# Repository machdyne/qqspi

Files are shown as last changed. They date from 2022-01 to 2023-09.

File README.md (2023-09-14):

# QQSPI Pmod&trade; compatible module

The QQSPI module provides access to four Quad SPI devices via a 12-pin Pmod&trade; compatible interface.

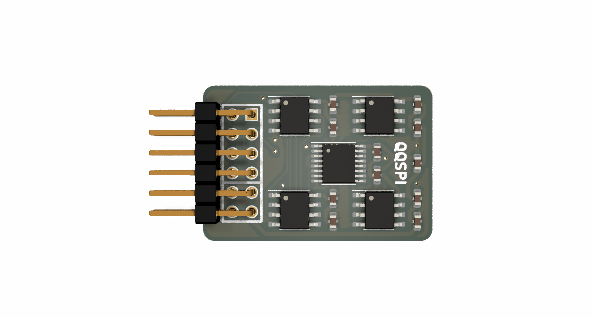
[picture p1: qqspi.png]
QQSPI


This repo contains schematics, pinouts and example Verilog code for the LD-QQSPI-PSRAM32 module.

Find more information on the [LD-QQSPI-PSRAM32 product page](https://machdyne.com/product/qqspi-psram32/).

## Modes

| PMOD/SS | PMODCS0 | PMODCS1 | -> | QSPI1/CE | QSPI2/CE | QSPI3/CE | QSPI4/CE |
| --- | --- | --- | -- | --- | --- | --- | --- |
| H | X | X | -> | H | H | H | H |
| L | L | L | -> | L | H | H | H |
| L | H | L | -> | H | L | H | H |
| L | L | H | -> | H | H | L | H |
| L | H | H | -> | H | H | H | L |

## Pinout

| Pin | Signal |
| --- | --- |
| 1 | /SS (active low) |
| 2 | SIO0 (MOSI) |
| 3 | SIO1 (MISO) |
| 4 | SCK |
| 5 | GND |
| 6 | 3V3 |
| 7 | SIO2 |
| 8 | SIO3 |
| 9 | CS0 |
| 10 | CS1 |
| 11 | GND |
| 12 | 3V3 |

## License

The contents of this repo are released under the [Lone Dynamics Open License](LICENSE.md) with the following exceptions:

- The KiCad design files contain parts of the [kicad-pmod](https://github.com/mithro/kicad-pmod) library which is released under the [Apache License, Version 2.0](https://www.apache.org/licenses/LICENSE-2.0.html).

- The KiCad design files may contain symbols and footprints released under other licenses; please contact us if we've failed to give proper attribution.

Note: You can use these designs for commercial purposes but we ask that instead of producing exact clones, that you either replace our trademarks and logos with your own or add your own next to ours.

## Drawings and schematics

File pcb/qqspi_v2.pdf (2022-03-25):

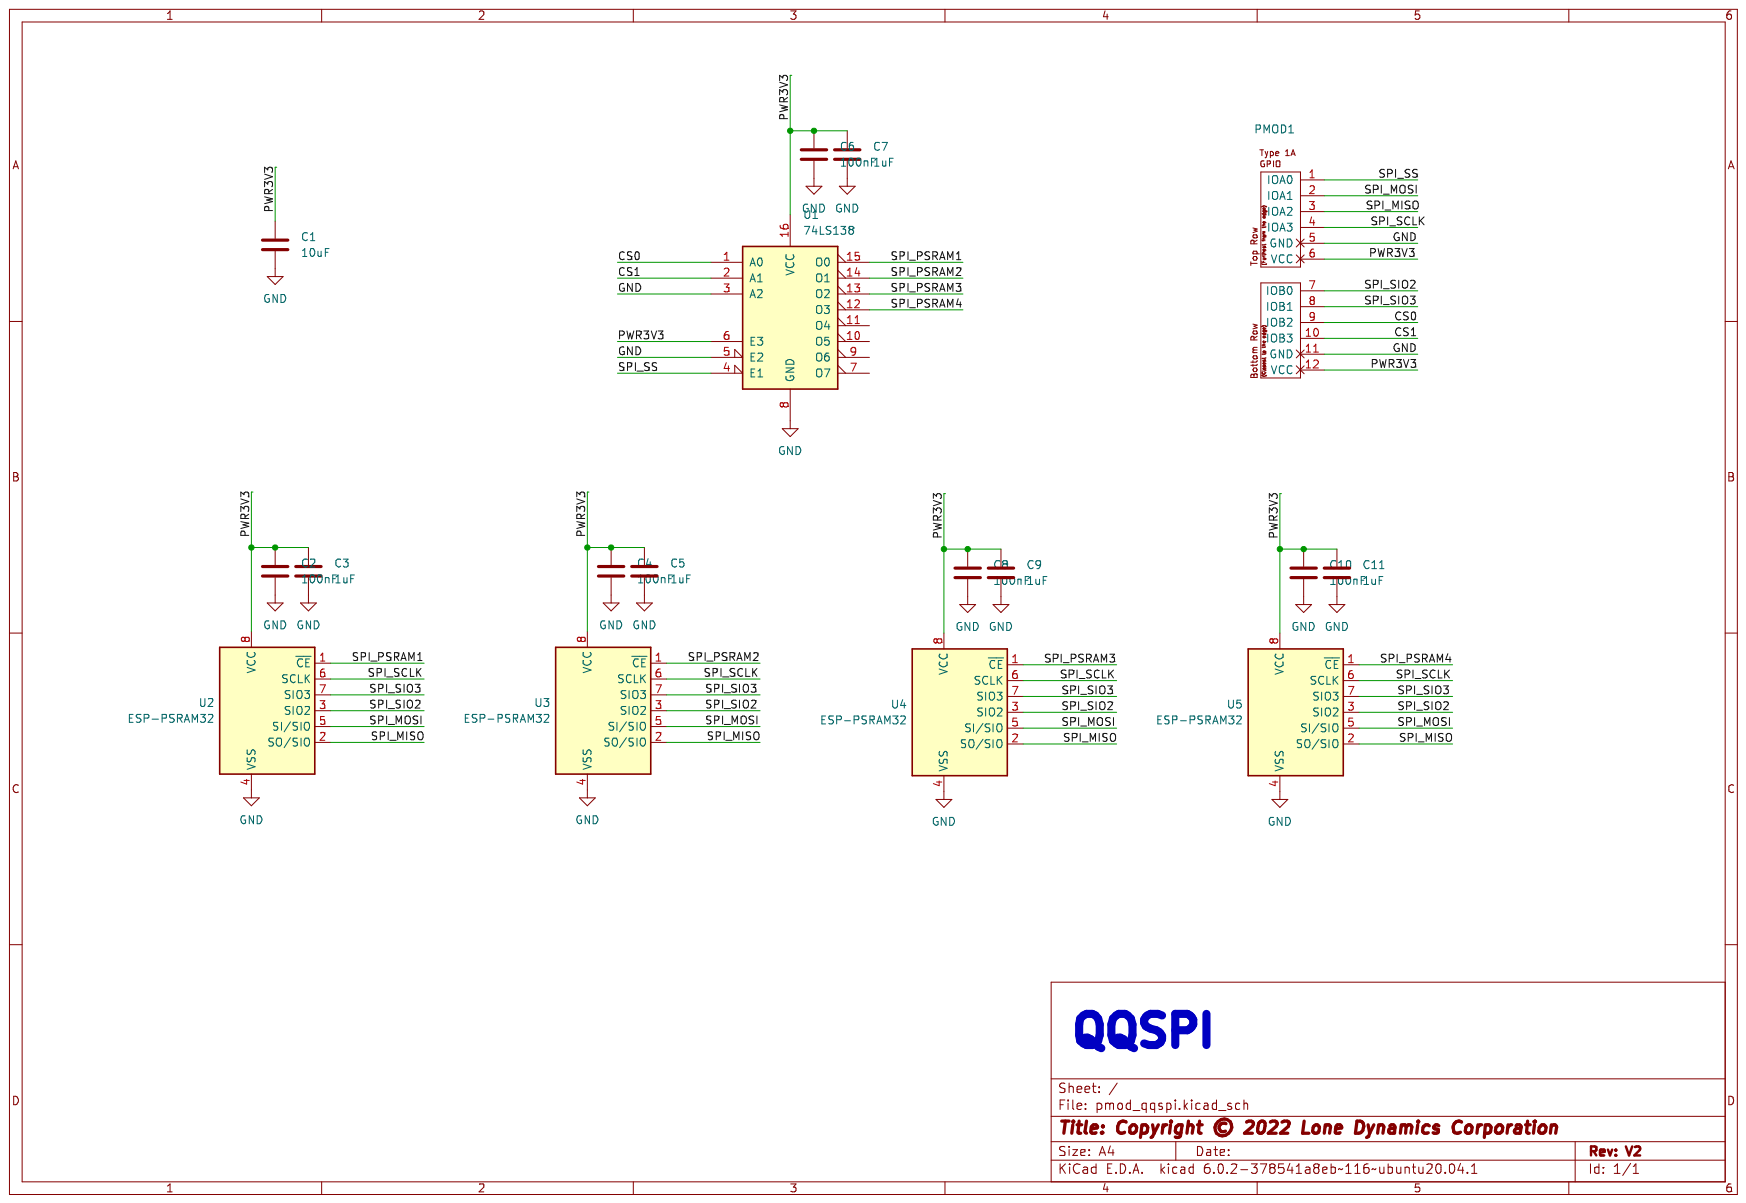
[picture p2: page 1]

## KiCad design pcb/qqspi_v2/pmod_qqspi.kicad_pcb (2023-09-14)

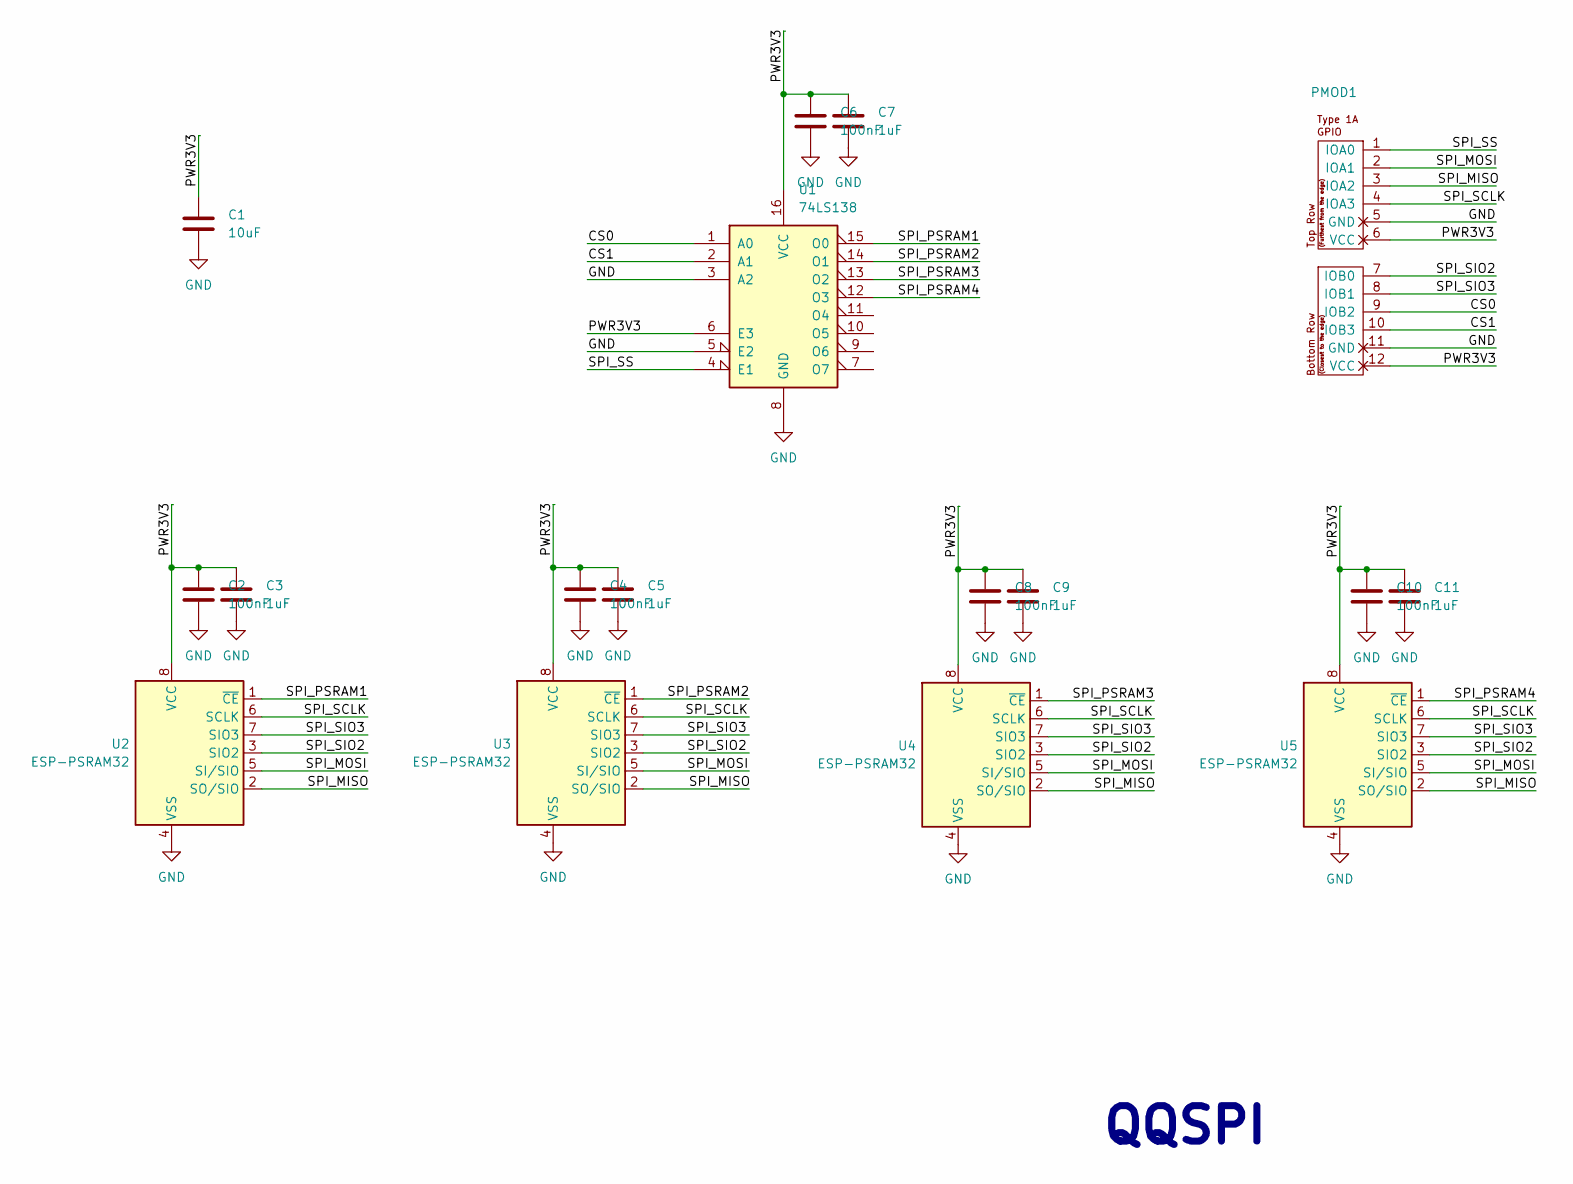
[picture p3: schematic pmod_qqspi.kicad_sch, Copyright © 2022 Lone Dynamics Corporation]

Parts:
C1: 10uF; C_0603_1608Metric
C2, C4, C6, C8, C10: 100nF; C_0603_1608Metric
C3, C5, C7, C9, C11: 1uF; C_0603_1608Metric
PMOD1: PMOD-Device-x2-Type-1A-GPIO; pmod_pin_array_6x2
U1: 74LS138; TSSOP-16_4.4x5mm_P0.65mm
U2, U3, U4, U5: ESP-PSRAM32; SOIC-8_3.9x4.9mm_P1.27mm

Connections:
/CS0: PMOD1.9 (IOB2), U1.1 (A0)
/CS1: PMOD1.10 (IOB3), U1.2 (A1)
/PWR3V3: C1.1, C2.1, C3.1, C4.1, C5.1, C6.1, C7.1, C8.1, C9.1, C10.1, C11.1, PMOD1.6 (VCC), PMOD1.12 (VCC), U1.6 (E3), U1.16 (VCC), U2.8 (VCC), U3.8 (VCC), U4.8 (VCC), U5.8 (VCC)
/SPI_MISO: PMOD1.3 (IOA2), U2.2 (SO/SIO), U3.2 (SO/SIO), U4.2 (SO/SIO), U5.2 (SO/SIO)
/SPI_MOSI: PMOD1.2 (IOA1), U2.5 (SI/SIO), U3.5 (SI/SIO), U4.5 (SI/SIO), U5.5 (SI/SIO)
/SPI_PSRAM1: U1.15 (O0), U2.1 (~CE)
/SPI_PSRAM2: U1.14 (O1), U3.1 (~CE)
/SPI_PSRAM3: U1.13 (O2), U4.1 (~CE)
/SPI_PSRAM4: U1.12 (O3), U5.1 (~CE)
/SPI_SCLK: PMOD1.4 (IOA3), U2.6 (SCLK), U3.6 (SCLK), U4.6 (SCLK), U5.6 (SCLK)
/SPI_SIO2: PMOD1.7 (IOB0), U2.3 (SIO2), U3.3 (SIO2), U4.3 (SIO2), U5.3 (SIO2)
/SPI_SIO3: PMOD1.8 (IOB1), U2.7 (SIO3), U3.7 (SIO3), U4.7 (SIO3), U5.7 (SIO3)
/SPI_SS: PMOD1.1 (IOA0), U1.4 (E1)
GND: C1.2, C2.2, C3.2, C4.2, C5.2, C6.2, C7.2, C8.2, C9.2, C10.2, C11.2, PMOD1.5 (GND), PMOD1.11 (GND), U1.3 (A2), U1.5 (E2), U1.8 (GND), U2.4 (VSS), U3.4 (VSS), U4.4 (VSS), U5.4 (VSS)

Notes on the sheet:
QQSPI

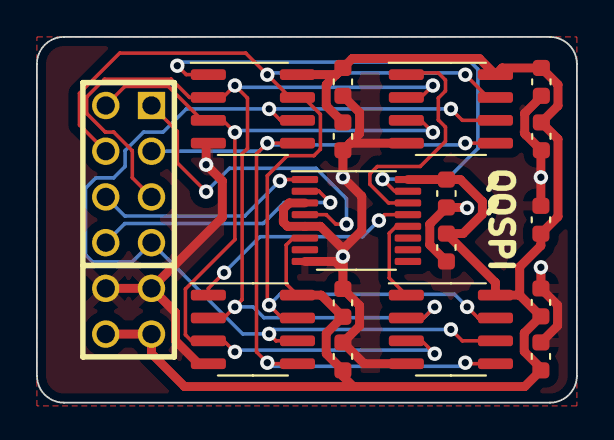
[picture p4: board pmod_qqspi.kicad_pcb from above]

Board: 2 copper layers, 30.0 x 20.3 mm, 17 parts (0 on the bottom side), 14 nets.

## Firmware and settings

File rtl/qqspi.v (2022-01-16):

/*
 * QQSPI
 * Copyright (c) 2021 Lone Dynamics Corporation. All rights reserved.
 *
 * Verilog module for interfacing the LD-QQSPI-PSRAM32 Pmod(tm) compatible
 * module with ICE40 FPGAs.
 *
 */

module qqspi #(
	parameter [0:0] QUAD_MODE = 1
)(

	input [31:0] addr,
	output reg [31:0] rdata,
	input [31:0] wdata,
	output reg ready,
	input valid,
	input write,
	input clk,
	input resetn,

	output reg ss,
	output reg sclk,
	inout mosi,
	inout miso,
	inout sio2,
	inout sio3,
	output reg [1:0] cs,
	output reg [2:0] state

);

	reg [3:0] sio_oe;
	reg [3:0] sio_do;
	wire [3:0] sio_di;

`ifdef TESTBENCH

	assign mosi = sio_oe[0] ? sio_do[0] : 1'bz;
	assign miso = sio_oe[1] ? sio_do[1] : 1'bz;
	assign sio2 = sio_oe[2] ? sio_do[2] : 1'bz;
	assign sio3 = sio_oe[3] ? sio_do[3] : 1'bz;

	assign sio_di = {sio3, sio2, miso, mosi};

`else

	SB_IO #(
		.PIN_TYPE(6'b1010_01),
		.PULLUP(1'b0)
	) qqspi_io [3:0] (
		.PACKAGE_PIN({sio3, sio2, miso, mosi}),
		.OUTPUT_ENABLE(sio_oe),
		.D_OUT_0(sio_do),
		.D_IN_0(sio_di)
	);

`endif

	localparam [2:0]
		STATE_IDLE			= 4'd0,
		STATE_INIT			= 4'd1,
		STATE_START			= 4'd2,
		STATE_CMD			= 4'd3,
		STATE_ADDR			= 4'd4,
		STATE_WAIT			= 4'd5,
		STATE_XFER			= 4'd6,
		STATE_END			= 4'd7;

	reg [31:0] buffer;
	reg [5:0] xfer_bits;
	reg xfer_quad;

	always @(posedge clk) begin

		if (!resetn) begin

			cs <= 2'b00;
			ss <= 1;
			sclk <= 0;
			sio_oe = 4'b1111;
			sio_do = 4'b0000;

			xfer_quad <= 0;
			xfer_bits <= 0;
			ready <= 0;

			state <= STATE_IDLE;

		end else if (valid && !ready && state == STATE_IDLE) begin

			state <= STATE_INIT;
			xfer_bits <= 0;

		end else if (!valid && ready) begin

			ready <= 0;

		end else if (xfer_bits) begin

			if (xfer_quad) begin
				sio_do[3:0] <= buffer[31:28];
			end else begin
				sio_do[0] <= buffer[31];
			end

			if (sclk) begin
				sclk <= 0;
			end else begin
				sclk <= 1;
				if (xfer_quad) begin
					buffer <= {buffer, sio_di[3:0]};
					xfer_bits <= xfer_bits - 4;
				end else begin
					buffer <= {buffer, sio_di[1]};
					xfer_bits <= xfer_bits - 1;
				end
			end

		end else case (state)

			STATE_IDLE: begin
				ss <= 1;
			end

			STATE_INIT: begin
				sio_oe <= 4'b0001;
				cs[1:0] <= addr[24:23];
				state <= STATE_START;
			end

			STATE_START: begin
				ss <= 0;
				state <= STATE_CMD;
			end

			STATE_CMD: begin
				if (QUAD_MODE)
					if (write) buffer[31:24] <= 8'h38; else buffer[31:24] <= 8'heb;
				else
					if (write) buffer[31:24] <= 8'h02; else buffer[31:24] <= 8'h03;
				xfer_bits <= 8;
				xfer_quad <= 0;
				state <= STATE_ADDR;
			end

			STATE_ADDR: begin
				buffer[31:8] <= { 1'b0, addr[22:0] };
				sio_oe <= 4'b1111;
				xfer_bits <= 24;
				if (QUAD_MODE)
					xfer_quad <= 1;
				if (QUAD_MODE && !write)
					state <= STATE_WAIT;
				else
					state <= STATE_XFER;
			end

			STATE_WAIT: begin
				sio_oe <= 4'b0000;
				xfer_bits <= 6;
				xfer_quad <= 0;
				state <= STATE_XFER;
			end

			STATE_XFER: begin
				if (QUAD_MODE)
					xfer_quad <= 1;
				if (write) begin
					sio_oe <= 4'b1111;
					buffer <= wdata;
				end else begin
					sio_oe <= 4'b0000;
				end
				xfer_bits <= 32;
				state <= STATE_END;
			end

			STATE_END: begin
				if (write)
					ss <= 1;
				else
					rdata <= buffer;
				ready <= 1;
				state <= STATE_IDLE;
			end

		endcase

	end

endmodule

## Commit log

2022-03-25 add v2 schematics
2023-09-14 add pcb layout
    [pmod_qqspi.kicad_pcb, pmod_qqspi.kicad_sch]
